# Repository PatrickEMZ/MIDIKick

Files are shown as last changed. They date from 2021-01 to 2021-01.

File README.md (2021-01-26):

# MIDIKick
Arduino based device to convert a Roland kick drum KT-10 signal into MIDI notes 

The motivation for this project comes from a personal need: I play drums in a band and during COVID we had a fex opportunities to rehearse at one place. However, I cannot take all my drum gear with me.
Especially the my bass drum. Having a Roland kick trigger pedal KT-10 and aan Elektron Digitakt I planned to use both. But Digitakt only has a MIDI input. Hence the need for an interafce.
And I find it fun to do during this lockdown / curfew time!

The simple architecture is represented in the following image
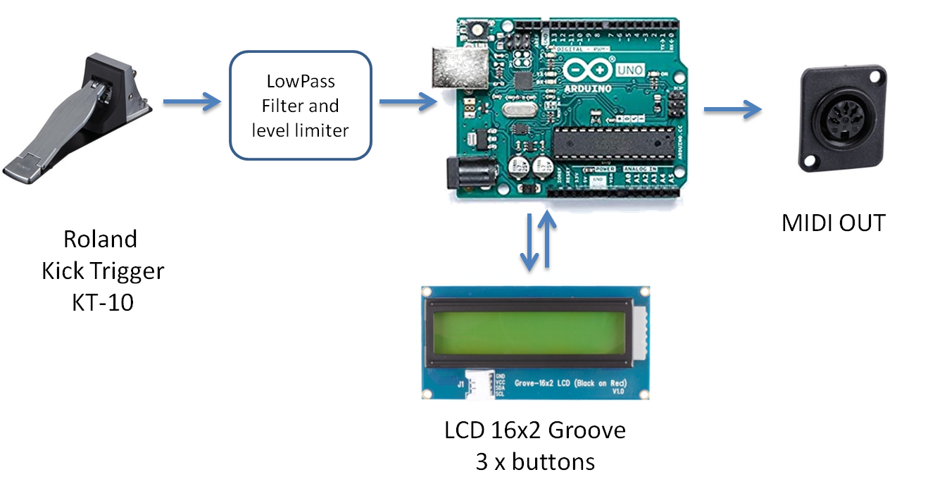
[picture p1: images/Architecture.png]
Architecture MidiKick


Here is the simple schematics associated with this project:
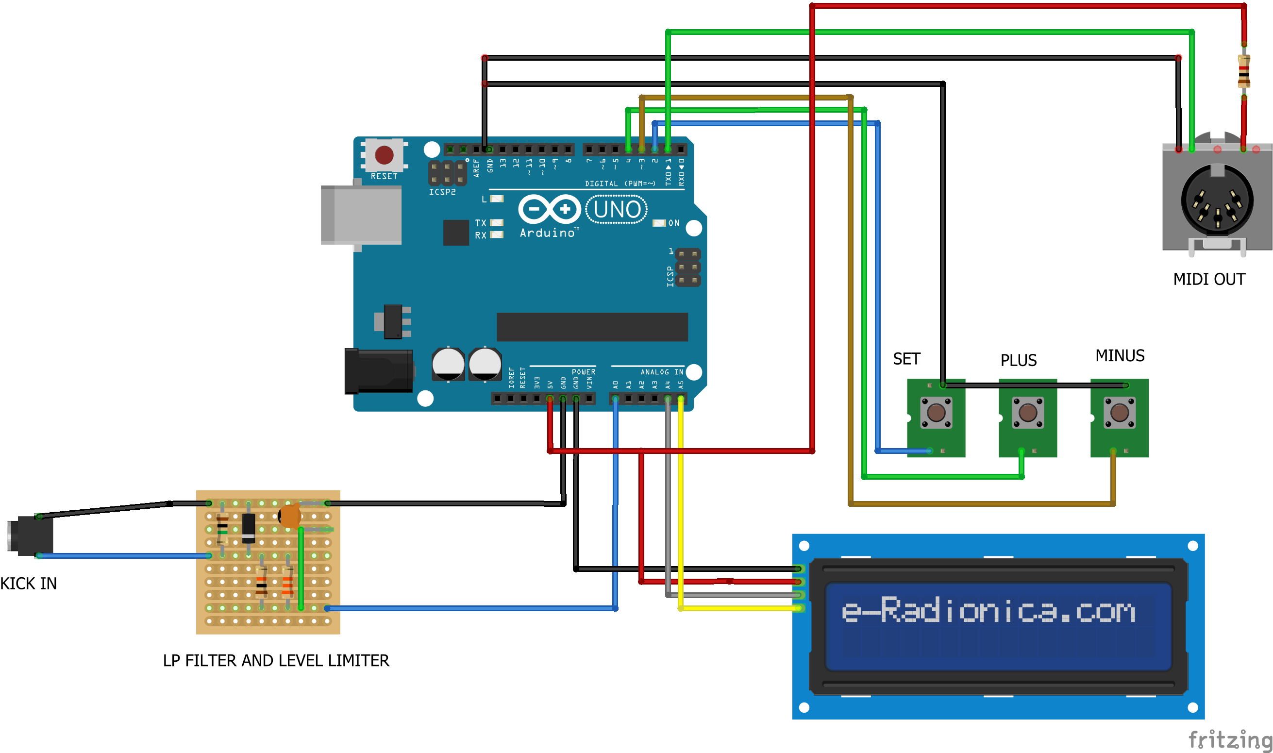
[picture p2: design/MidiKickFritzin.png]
Schematics MidiKick


The LowPass filter and level limiter are very simple, and values have been chose by measuring the effects. A digital LPF would have been better, but I have limited time to do this and have zero experience on Arduino. I suspect real time issues, so you are welcome to try this!

The core algortithm is quite straightforward:
- acquisition of value
- if value is gretaer thean threshold, wait for maximum (we estimate when the acquired value starts to go down) and send MIDI NOTE ON
- when value goes below threshold, send MIDI NOTE OFF
- wait for short delay to absorb remaining oscillations
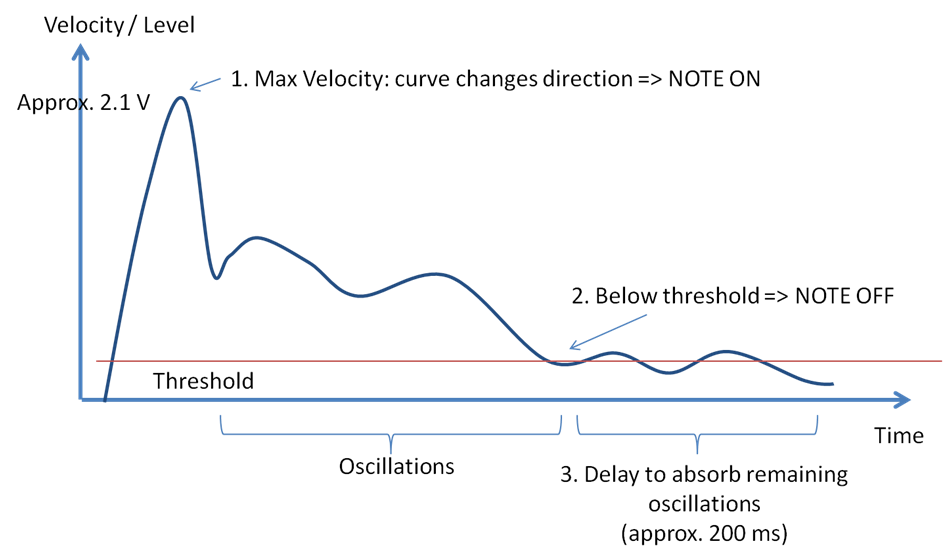
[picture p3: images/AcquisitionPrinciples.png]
Algorithm principles


Additional features are:
- change of NOTE: you can choose which note to play C0 to G10
- choice of MIDI channel :1 to 16
- choice of velocity curve: log, exponential, linear
- max velocity 1 to 128

The UI is based on some GUI tools I had designed before. Probably not optimal, but it works!

What you will need to build this:
* Arduino Uno (could probably work with a smaller Arduino)
* 1 female Jack 1/4 (6.3 mm)
* 1 female DIN 5 (MIDI)
* Resistors
  * 1 x 1 Mohm
  * 1 x 33 Kohm
  * 1 x 10 Kohm
  * 1 x 1Kohm
* Capacitor
  * 1 x 330 nF
* Diodes
  * 1 x Zener 4.7 V
* 1 LCD Display 16 x 2 (in my case Grove LCD RGB backlight)
* 3 x push buttons , 1 contact
* wires to connect all components
* 1 x USB power supply for Arduino
* 1 x MIDI cable
* 1 x male male 1/4 cable for kick drum connection

Additional libraries:
* The LinkedList library even though I do not use it in this case... [Download](https://github.com/ivanseidel/LinkedList/archive/master.zip)
* The LCD library (to be replaced by a compatible one if you use another type of LCD) [Grove LCD](https://github.com/Seeed-Studio/Grove_LCD_RGB_Backlight/archive/master.zip)

This design can certainly be enhanced, especially if you would like to adapt it to other piezos. There are mutiple examples you can get inspiration from, you are welcome to do this.

Licence: the code, all graphics and documents are under "Attribution 4.0 International (CC BY 4.0)" licence [licence](https://creativecommons.org/licenses/by/4.0/legalcode)

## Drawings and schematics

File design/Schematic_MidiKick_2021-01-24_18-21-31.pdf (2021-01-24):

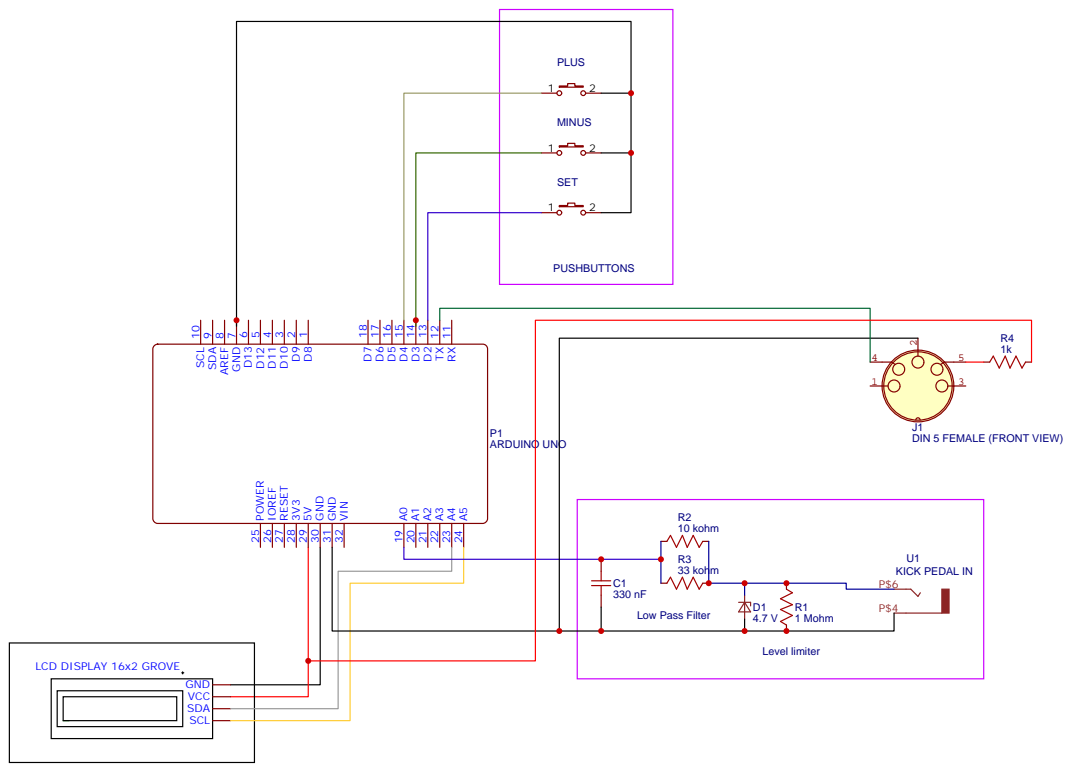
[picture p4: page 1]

DIN 5 FEMALE (FRONT VIEW)

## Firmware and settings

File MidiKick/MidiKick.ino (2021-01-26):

// -*-c++-*-
// MidiKick Your Ass!
//  This application has been designed to transform the signal coming
// from a Roland kick pedal into a MIDI note.
//
// Version: 1.0
// Author: Patrick E. Mazeau
// Features are:
// - possibility to change the note, the MIDI channel
// - possibility to choose Velocity curve (log, exp, linear)
// - possibility to fix max velocity
//
// This has been tested with the Roland kick pedal but could be adapted for other types of piezo
//
// Possible improvements:
// - memory: much too much
// - low kicks not taken into account: see if Arduino AD converted can be tweaked to increase resolution. The current
// signal after LP filter is 2.4 V peaks, not 5V as Arduino A0 input can convert
// - digital LP filter rather than electronic: had no time to experiement with that
//
// Licence:
// - Attribution 4.0 International (CC BY 4.0):
//   You are free to:
//     Share — copy and redistribute the material in any medium or format
//     Adapt — remix, transform, and build upon the material for any purpose, even commercially.
//   Under the following terms:
//     Attribution — You must give appropriate credit, provide a link to the license, and indicate if changes were made.
//            You may do so in any reasonable manner, but not in any way that suggests the licensor endorses you or your use.
//     No additional restrictions — You may not apply legal terms or technological measures that legally restrict others from doing anything the license permits.
//


// #include <MemoryFree.h>
#include <math.h>
#include <Wire.h>
// #include <Time.h>
#include <avr/wdt.h>

// using this RGB library linked to the Grove 16X2 LCD I got from seedstudio wiki.seedstudio.com
#include <rgb_lcd.h>

// my own tools for UI manipulation, not a library et
#include "ElementUI.h"
#include "UIMidiKick.h"
#include "Memory.h"

// versionSoftware of Midikick, eraseed when starting
char versionSoftware [] = "MidiKick 1.0";

// My LCD version is only RED, so possibility to dim erase. 
const int colorR = 255;
const int colorG = 0;
const int colorB = 0;

// variable for EEPROM memory
EEmemory * myMemory = 0;

// strange, need to use an intermediate variable otherwise get compile error with static variable
rgb_lcd lcd;
rgb_lcd *toto = &lcd;
rgb_lcd  *BaseVisu::myLcd = toto;
BaseVisu *BaseVisu::activeItem = 0;

// 3 UI push buttons: 
// - PIN 2 Set
// - PIN 3 Right/-
// - PIN 4 Left/+
#define pinButtonSet 2
#define pinButtonMinus 3
#define pinButtonPlus 4

// ts keeps track of time when Arduino boots
// unsigned long ts = millis();

// line1 and line2 used as buffers for 2 lines of LCD
char ligne1[17];
char ligne2[17];

// clearline: cleans line linno on LCD
void clearLine (int linno);

// additional characters for LCD: menuIcon, VuMeter

byte backslashIcon[8]={
		   B00000,
		   B10000,
		   B01000,
		   B00100,
		   B00010,
		   B00001,
		   B00000,
		   B00000,
};

byte menuIcon[8]={
		   B11111,
		   B10001,
		   B11111,
		   B10001,
		   B11111,
		   B10001,
		   B11111,
		   B00000,
};

byte logIcon[8]={
		   B00111,
		   B01000,
		   B01000,
		   B10000,
		   B10000,
		   B10000,
		   B10000,
		   B00000,
};
		 
byte expIcon[8]={
		   B00001,
		   B00001,
		   B00001,
		   B00001,
		   B00010,
		   B00010,
		   B11100,
		   B00000,
};

byte linIcon[8]={
		   B00000,
		   B00001,
		   B00010,
		   B00100,
		   B01000,
		   B10000,
		   B00000,
		   B00000,
};

byte vm1Icon[8]={
		   B00000,
		   B11111,
		   B11111,
		   B11111,
		   B11111,
		   B11111,
		   B11111,
		   B00000,
};

byte vm2Icon[8]={
		   B11000,
		   B11000,
		   B11000,
		   B11000,
		   B11000,
		   B11000,
		   B11000,
		   B11000,
};

byte vm3Icon[8]={
		   B00000,
		   B00000,
		   B00000,
		   B00000,
		   B00000,
		   B00000,
		   B00000,
		   B00000,
};


// Pin used for kick AD acquisition
#define kickPin  0

// analog threshold for kick sensing
#define PIEZOTHRESHOLD 10

// max value of kick after filtering, what I measured with the Roland kick
int maxPiezo = 220 ;

// variables for dealing with acquisition loop, threshold, slope detection
int val = 0;
float f = 0;
int maxFrappe = 0;
bool noteStatus = false;
// values contains the first sizeValues, for future use like digital LP filtering, or slope detection, or debug 
#define sizeValues 50
int values [sizeValues];
int i=0;
int k=0;
bool bassStart = false;
int numDescentes = 0;
int vuMeterDelay = 0;

// mainWindow: keeps track of the start screen
MainWindow * mainWindow = 0;


void setup() {
  // variable to check if it is first use, or request for reset
  bool estResetUsine = false;

  // MIDI INIT, set MIDI speed
  Serial.begin(31250);
  // for debugging uncomment following line, we print results on serial window
  // Serial.begin(38400);

  // set up the LCD's number of columns and rows:
  lcd.begin(16, 2);
  lcd.setRGB(colorR, colorG, colorB);
  // creation of backslash character
  lcd.createChar(0, backslashIcon);
  // creation menu character
  lcd.createChar(1, menuIcon);
  // creation characters for velocity curves
  lcd.createChar(2, logIcon);
  lcd.createChar(3, expIcon);
  lcd.createChar(4, linIcon);
  // creation characters for vumeter
  lcd.createChar(5, vm1Icon);
  lcd.createChar(6, vm2Icon);
  lcd.createChar(7, vm3Icon);

  //***************************************************
  // EEPROM initialisation
  // - default values stored in EEPROM if first use, or factory reset
  // - adresses of EEPROM stored in myMemory
  estResetUsine = EEmemory::isNew();

  // check first use / factory reset, erase messages
  if ( estResetUsine ) {
    lcd.clear();
    lcd.setCursor(0,0);
    lcd.print("WELCOME!");
    lcd.setCursor(0,1);
    lcd.print("FACTORY RESET");
    delay (2000);
  }
  
  // Print a message to the LCD.
  lcd.clear();
  lcd.print(versionSoftware);
  lcd.setCursor(0,1);
  lcd.print("Init...");
  delay (2000);

  myMemory = new EEmemory();

  // GUI initialisation
  
  // button initialisation
  pinMode(pinButtonSet,INPUT_PULLUP);
  pinMode(pinButtonPlus,INPUT_PULLUP);
  pinMode(pinButtonMinus,INPUT_PULLUP);

  // ts = millis();
  
  // WATCHDOG configuration
  // 8 seconds
  cli();
  wdt_reset();
  /*
    WDTCSR configuration:
    WDIE = 1: Interrupt Enable
    WDE = 1 :Reset Enable
    See table for time-out variations:
    WDP3 = 0 :For 2000ms Time-out
    WDP2 = 1 :For 2000ms Time-out
    WDP1 = 1 :For 2000ms Time-out
    WDP0 = 1 :For 2000ms Time-out
  */
  // Enter Watchdog Configuration mode:
  WDTCSR |= (1<<WDCE) | (1<<WDE);
  // Set Watchdog settings:
  WDTCSR = (1<<WDIE) | (1<<WDE) |
    (1<<WDP3) | (0<<WDP2) | (0<<WDP1) |
    (1<<WDP0);
  sei();

  // seems to be needed after factory reset...
  delay(100);
  
  // Global windows initialisation
  mainWindow = new MainWindow ();
  BaseVisu::activeItem = mainWindow;
  mainWindow->display();
}

void loop() {
  // ***********************
  // MIDI part
  //

  // char buf[10]; // for debug
   
  int velocity = 0;

  // kick value acquisition
  val = analogRead(kickPin);

  // experiemental: every X count we display something on VuMeter, otherzise too slow
  if ( vuMeterDelay == 210 ) {
    if (  BaseVisu::activeItem == mainWindow )
      mainWindow->itemVuMeter->display();
    vuMeterDelay=0;
  }
  else
    vuMeterDelay++;
  
  // kick is >= Threshold and we did not start acquisition yet
  if( val >= PIEZOTHRESHOLD && !bassStart) {
    bassStart = true ;
    maxFrappe= 0;
    noteStatus = false;
    i = 0;
  }
    
  // kick acquisition has started and still >= Threshold
  if( val >= PIEZOTHRESHOLD && bassStart) {
    // The kick curve has a peak, then oscillations
    // - when we start to see a descent, we have reached the max velocity and we send NoteOn
    // - we wait until we go below Threshold
    // - we store values in values to compute descent, i is the current index

    //sprintf(buf,"%i",val);
    //Serial.println(buf);
    if ( i < sizeValues) {
      values [i] = val;
      if ( val > maxFrappe) {
	maxFrappe = val;
      }
      if ( sensPente (i) == -1 ) {
	// First descent, we reached maximum, on send NOTE ON
	if ( numDescentes == 0 ) {
	  numDescentes++;
	  // we check the type of velocity curve and compute the right velocity value
	  if ( myMemory->curbVelocity.get() == VELOCITYLOG)
	    velocity = (int)(log10 (maxFrappe) / log10 (maxPiezo) * myMemory->maxVelocity.get());
	  if ( myMemory->curbVelocity.get() == VELOCITYEXP)
	    velocity =(int)(pow(2.71828, ((float)maxFrappe) / maxPiezo * log (myMemory->maxVelocity.get())));
	  if ( myMemory->curbVelocity.get() == VELOCITYLIN)
	    velocity =(int)(((float)maxFrappe) / maxPiezo * myMemory->maxVelocity.get());
	  
	  if ( velocity > myMemory->maxVelocity.get())
	    velocity = myMemory->maxVelocity.get();
	  noteOn(myMemory->midiCh.get()-1,myMemory->midiNote.get(), velocity );
	  noteStatus = true;
	  //char buf[10];
	  // snprintf(buf,10,"%i",val);
	  // Serial.println(buf);

 	}
      }
      i++;
    }
  }
    
  // acquisition< Threshold, and we started acquiring, we send NOTE OFF
  if( val < PIEZOTHRESHOLD && bassStart) {
    // snprintf(buf,10,"%i",val);
    // Serial.println(buf);

    if (noteStatus) {
      noteOff(myMemory->midiCh.get()-1,myMemory->midiNote.get(), 0);
    }
    bassStart = false ;
    numDescentes = 0;

    // short delay (experiemental) to avoid additional oscillations
    delay(50);
  }

  
  //************************
  // GUI part
  // We check which button has been called, send appropirate method to active GUI item (window, menu etc)

  // set button
  if (digitalRead(pinButtonSet) == LOW) {
    if ( BaseVisu::activeItem ) {
      BaseVisu::activeItem->set();
    }
    delay(200);
  }
  // PLUS button
  if(digitalRead(pinButtonPlus)==LOW) {
    if ( BaseVisu::activeItem) {
      BaseVisu::activeItem->plus();
    }
    delay(200);
  }
  
  // MINUS button
  if(digitalRead(pinButtonMinus)==LOW) {
    if ( BaseVisu::activeItem) {
      BaseVisu::activeItem->minus();
    }
    delay(200);
  }

  wdt_reset();
}

// Send a MIDI note-on message
void noteOn(byte channel, byte note, byte velocity) {
  // for debugging
  //midiMsg2( (0x90 | channel), note, velocity);
  midiMsg( (0x90 | channel), note, velocity);
}

// Send a MIDI note-off message
void noteOff(byte channel, byte note, byte velocity) {
  // for debugging
  //midiMsg2( (0x80 | channel), note, velocity);
  midiMsg( (0x80 | channel), note, velocity);
}

// Send a MIDI message
void midiMsg(byte cmd, byte data1, byte data2) {
  Serial.write(cmd);
  Serial.write(data1);
  Serial.write(data2);
}

// Print a MIDI message
void midiMsg2(byte cmd, byte data1, byte data2) {
   Serial.println( "Commande MIDI:");
   Serial.print(cmd, HEX);
   Serial.print(" ");
   Serial.print(data1, HEX);
   Serial.print(" ");
   Serial.print(data2, HEX);
   Serial.println( " ");
}

// sensPente: function computing the curve direction over n number of samples
// 1: UP
// -1: DOWN
// 0: not significant
int sensPente (int ind1) {
  if ( ind1 < 1 )
    return 0;
  if ( values [ind1] > values [ind1 -1])
    return 1;
  if ( values [ind1] <= values [ind1 -1])
    return -1;
  return 0;
  // if ( ind1 < 3 )
  //   return 0;
  // if ( values [ind1] > values [ind1 -1] &&
  //      values [ind1 -1] > values [ind1 -2] &&
  //      values [ind1 -2] > values [ind1 -3])
  //   return 1;
  // if ( values [ind1] < values [ind1 -1] &&
  //      values [ind1 -1] <values [ind1 -2] &&
  //      values [ind1 -2] < values [ind1 -3])
  //   return -1;
  // return 0;
}
 

// clearLine: clears line linno on LCD
void clearLine (int linno) {
    lcd.setCursor (0,linno);
    lcd.print (F("                "));
    lcd.setCursor (0,linno);
}

// interruption called in case of WATCHDOG
ISR (WDT_vect) {
  lcd.setCursor(0,1);
  lcd.print ("RESET!!!!       ");
}

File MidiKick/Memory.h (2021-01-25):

// -*-c++-*-
// Memory: class to manage access to EEPROM
//
// Licence:
// - Attribution 4.0 International (CC BY 4.0):
//   You are free to:
//     Share — copy and redistribute the material in any medium or format
//     Adapt — remix, transform, and build upon the material for any purpose, even commercially.
//   Under the following terms:
//     Attribution — You must give appropriate credit, provide a link to the license, and indicate if changes were made.
//            You may do so in any reasonable manner, but not in any way that suggests the licensor endorses you or your use.
//     No additional restrictions — You may not apply legal terms or technological measures that legally restrict others from doing anything the license permits.
//

#ifndef MEMORY_H
#define MEMORY_H

#include <EEPROM.h>

// default values for stored variables
// midi channel
#define MIDICH 10
// midi note for kick
#define MIDINOTE 35
// max velocity
#define MAXVELOCITY 127
// types of velocity curves
#define VELOCITYLOG 0
#define VELOCITYLIN 1
#define VELOCITYEXP 2
// default velocity
#define VELOCITYDEFAULT VELOCITYLOG
// MAGIC number for checking FACTORY RESET
#define MAGIC 16712


// classes to manage EEPROM variables
// Int
class EEint {
public:
  EEint (){};
  int adresse;
  virtual set(int _val){EEPROM.put (adresse, _val);};
  virtual int get (){int val=0;EEPROM.get (adresse, val); return val;};
};

// Long
class EElong {
public:
  EElong(){};
  int adresse;
  virtual set(long _val){EEPROM.put (adresse, _val);};
  virtual long get (){long val=0;EEPROM.get (adresse, val); return val;};
};

// memory class
class EEmemory {
public:
  EEmemory();
  static bool isNew ();
  init();
  initAdresses();
  reset();
  resetFactory();
  EEint midiCh;
  EEint midiNote;
  EEint maxVelocity;
  EEint curbVelocity;
};

#endif  
